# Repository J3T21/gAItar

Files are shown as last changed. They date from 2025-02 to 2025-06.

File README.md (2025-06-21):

# gAItar
Final Year Masters Electronic and Information Engineering project: A mechatronic interface to play an acoustic guitar with some AI elements.

gAItar Demo Video (https://youtu.be/pzkTf3Y7SAQ)

## User Guide

### Introduction
Welcome to gAItar! This guide will help you understand how to set up and use the gAItar system.

### Setup Instructions

#### Software Setup

##### Backend API (`gAItar_api`)
1.  Navigate to the `gAItar_api/backend` directory in your terminal.
2.  It's recommended to create and activate a Python virtual environment:
    *   `python -m venv venv`
    *   On Windows: `venv\Scripts\activate`
    *   On macOS/Linux: `source venv/bin/activate`
3.  Install Python dependencies: `pip install -r requirements.txt` (Ensure you have a `requirements.txt` file in this directory listing libraries like `fastapi`, `uvicorn`, `torch`, `huggingface_hub`, `python-multipart`, `mido`, `miditok`, `basic-pitch`, `tensorflow`, `pretty_midi`).
4.  Run the FastAPI server: `uvicorn main:app --reload`
    *   The API will be available at `http://localhost:8000`.

##### User Interface (`UI/gaitar_ui`)
1.  Navigate to the `UI/gaitar_ui` directory in your terminal.
2.  Install Node.js dependencies: `npm install`
3.  Start the development server: `npm start`
    *   The UI will be accessible at `http://localhost:3000`.
4.  **Important:** Verify and update the API base URLs in `UI/gaitar_ui/src/api.js`:
    *   `backend_api`: Should point to your backend API (e.g., `http://localhost:8000`).
    *   `esp32`: Should point to your ESP32's IP address (e.g., `http://192.168.113.200`).

##### ESP32 Firmware (`gAItar_esp32`)
1.  Open the `gAItar_esp32` project folder in VS Code with PlatformIO extension.
2.  In `gAItar_esp32/src/main.cpp`:
    *   Update the `ssid` and `password` variables with your Wi-Fi network credentials. The current configuration is set for an Android mobile hotspot. Ensure this network is the same one your computer (running the UI and backend) is connected to.
    *   The ESP32 attempts to configure a static IP address (e.g., `192.168.113.200` as seen in the code). The actual IP address will be displayed in the Serial Monitor upon successful connection. Ensure this IP matches the `baseURL` for `esp32` in `UI/gaitar_ui/src/api.js`. Also change this to match the websockets in the `upload.js` and `playbackinfo.js` components (this caused me much pain in the past).
    *   3.  Build and upload the firmware to the ESP32 board using PlatformIO.

##### Adafruit Grand Central Firmware (`gAItar_arduino`)
1.  Open the `gAItar_arduino` project folder in VS Code with PlatformIO extension.
2.  The firmware should generally not require changes for basic operation. Pin assignments for solenoids and servos are defined in `gAItar_arduino/src/globals.cpp`. Ensure these match your physical wiring.
3.  Build and upload the firmware to the Adafruit Grand Central board using PlatformIO.

### Using the gAItar Interface

#### Main Interface Overview
*   **Search & Playlist:**
    *   Use the search bar to find songs by title.
    *   Filter songs by artist or genre using the dropdowns.
    *   Click "Play" to play a song immediately or "Add to Playlist" to add it to the current queue.
    *   Manage the current playlist (e.g., reorder, remove songs).
*   **Playback Controls:**
    *   Use the Play, Pause, Skip Forward, Skip Backward, and Shuffle buttons to control playback on the physical guitar.
*   **MIDI Generation (`GenMIDI`):**
    *   Enter a text prompt describing the music you want to generate (e.g., "a sad blues riff in E minor").
    *   Click "Generate MIDI". The generated MIDI can be played in the browser or uploaded to the song upload form.
*   **Song Upload (`Upload`):**
    *   Select a MIDI file (`.mid` or `.midi`).
    *   Enter the Title, Artist, and Genre for the song.
    *   You can add new artists or genres if they are not in the existing dropdowns.
    *   Click "Upload". This will send the MIDI to the backend for processing and then transfer the processed data to the ESP32.
*   **Voice to MIDI (`VoiceToMIDI`):**
    *   Record audio using your microphone.
    *   Convert the recorded audio to a MIDI file.
    *   The generated MIDI can be played, downloaded, or sent to the Upload form.
*   **Voice Control:**
    *   Use voice commands to control playback (e.g., "Play song [Title]", "Pause", "Next song"). Refer to the UI for available commands and status.

### Troubleshooting
*   **Cannot connect to ESP32:**
    *   Verify the ESP32's IP address in `UI/gaitar_ui/src/api.js` matches the IP shown in the ESP32's serial output.
    *   Ensure the ESP32 is connected to the same Wi-Fi network as the computer running the UI.
    *   Check the ESP32 serial monitor for error messages (e.g., Wi-Fi connection issues, SPIFFS errors).
*   **MIDI generation fails:**
    *   Ensure the backend API (`gAItar_api`) is running and accessible at `http://localhost:8000`.
    *   Check the backend console for error messages (e.g., model loading issues, Hugging Face Hub connection).
*   **Song upload fails:**
    *   Ensure both the backend API and ESP32 are operational and connected.
    *   Check the browser console, backend console, and ESP32 serial monitor for specific error messages.
    *   Verify SPIFFS on the ESP32 is working correctly (it's formatted on ESP32 startup).
*   **Playback issues on the guitar:**
    *   Check wiring to solenoids and servos.
    *   Verify pin configurations in `gAItar_arduino/src/globals.cpp`.
    *   Monitor serial output from the Adafruit Grand Central for any errors during playback.

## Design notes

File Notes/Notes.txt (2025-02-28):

Mini solenoids seem to be just about strong enough
Need 5v for gate of current mosfets - could get 3.3V Vth https://www.mouser.co.uk/ProductDetail/Infineon-Technologies/IRFZ34NPBF?qs=9%252BKlkBgLFf3Kc9ZWbyua6Q%3D%3D
Guitar thickness = 11.3cm, 4cm between inner servo flanges, 3cm between 2 consecutive servo flanges, servo 17mm thick, m2.5 bolt holes, height above guitar lower edge 19mm, bar thickness <15mm, body to hole center ~3mm maybe check.
Guitar width ~30cm
https://github.com/natecdr/tuttut midi -> tab

1. get single channel guitar only midi (python)
2. convert to intermediate representation string and fret number greedy? (python)
3. read intermediate representation (cpp)
4. convert to movements/or sounds in model(cpp)

1. Can either be different tracs for different instruments or single track, just merge and get rid of non guitar sounds (at least for now)
Program_change messages specify which channel contains which instrument, use this to filter
2. Note assigning algorithm deal with decisions/conflicts. start with classical midi for algo dev -strictly guitar

https://www.twilio.com/en-us/blog/working-with-midi-data-in-python-using-mido

around delay of 60 seems to be min delay
if notes are "simultaneous" delay after all simultaneous notes (no delays in between).

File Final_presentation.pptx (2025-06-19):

## gAItar

A robotically actuated acoustic guitar with generative AI

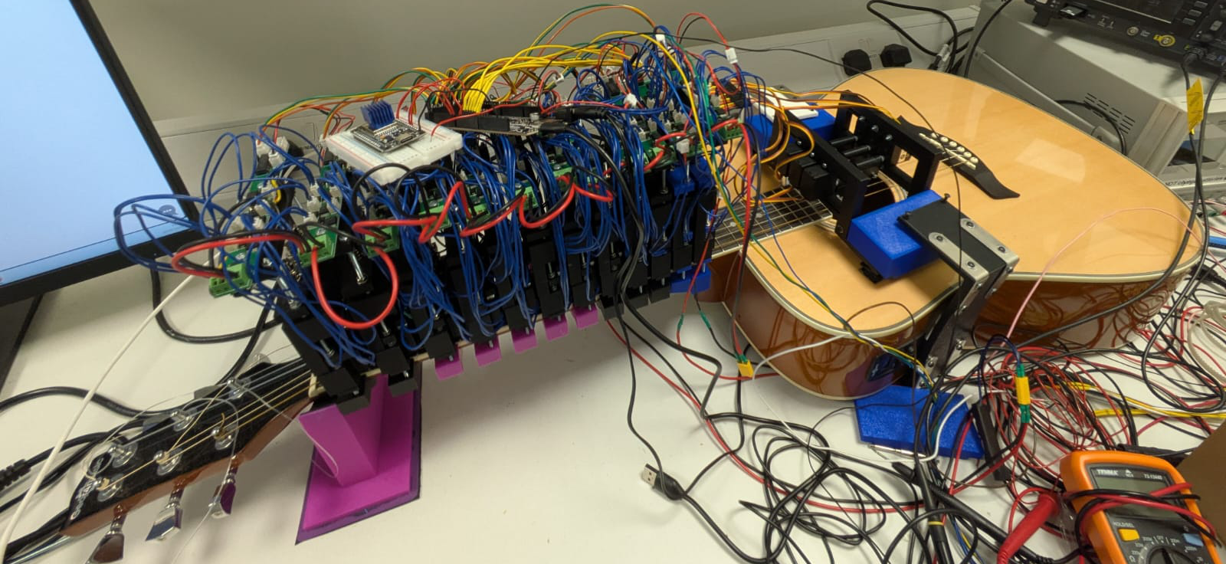
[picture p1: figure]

## Video Demonstration

https://youtu.be/pzkTf3Y7SAQ

## System Overview

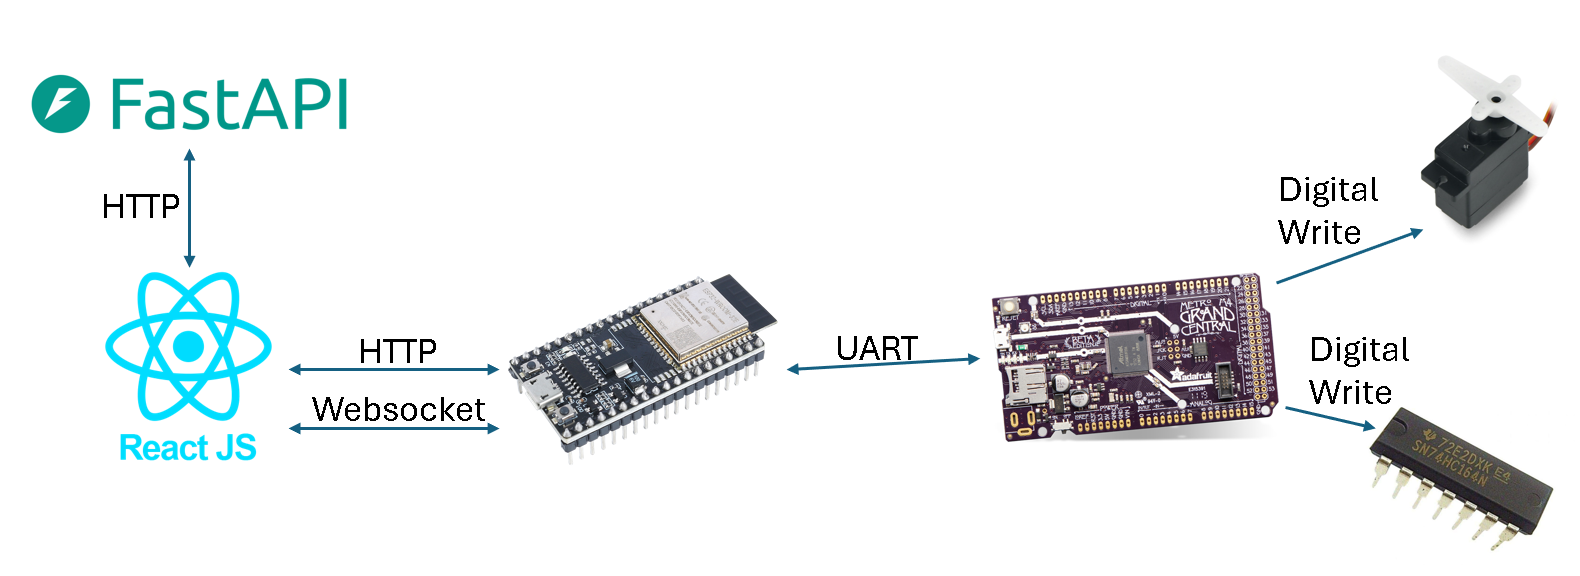
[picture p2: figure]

## Backend endpoints

POST /upload-midi-binary
POST /upload-midi (legacy)
POST /generate-midi/
Post /convert-audio-to-midi/

## /upload-midi-binary overview

Endpoint: POST /upload-midi-binary
Receives: A user-uploaded MIDI file and its song metadata.
Translates: Converts MIDI notes into a playable sequence of guitar events (string, fret, time).
Optimizes: Serializes these events into a custom, highly compact binary format designed for the microcontroller's limited memory.
Delivers: Returns the binary data to the frontend for transfer to the ESP32.

## MIDI to Guitar

Metadata extraction
Note to guitar mapping
Melodic track isolation
Merging and time normalisation
Event encoding
JSON formatting
Extract global timing info
Remove percussion (MIDI track 9) and empty tracks
Combine melodic tracks, convert time to absolute ms
Greedy algorithm to map not to string, fret pair, lowest note first
Encode each note on and off event: Timing, string number, fret number
Sort events chronologically and wrap into JSON structure

## Playback instruction format

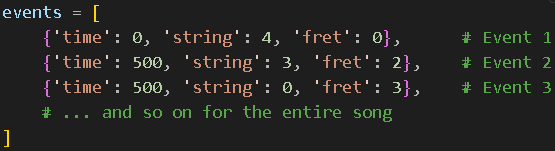
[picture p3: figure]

JSON event format

30x reduction in file sizes

Binary encoding

Byte 0 | Byte 1 | Byte 2 | Byte 3 | Byte 4
Time ms (unsigned long) | | | | Guitar Mapping

Byte 4
Bit 7 | Bit 6 | Bit 5 | Bit 4 | Bit 3 | Bit 2 | Bit 1 | Bit 0
0 | 1 | 1 | 0 | 0 | 0 | 1 | 0
String = [7:5] | | | Fret = [4:0]

## /generate-midi/ overview

User input
JSON payload from React.js frontend
Model inference
Text2midi T5 transformer model
Token generation
Text based musical tokens
Decode to midi
Miditok library used to turn tokens into midi file
Output
MIDI file returned to frontend

Text2midi neural network usage

## /audio-to-midi/ overview

User Input
Upload
Output
Clip recorded as wav file from frontend
Wav file is uploaded to /audio-to-midi/ endpoint
Automated Musical Transcription (AMT)
Basic Pitch Neural network by Spotify research MIDI output
Send MIDI file to frontend for user decision

## Frontend overview (React.js)

Controls.js
Playback controls
Search.js
Search and filter for songs
Playlist.js
Manages song queue
Upload.js
Form for upload, posts to backend, websocket for progress
GenMIDI.js
Generate MIDI from text prompt, posts text to backend
VoiceToMIDI.js
User microphone input, sends recording to backend for MIDI transcription
VoiceControl.js
Uses browser Speech Recognition API to respond to commands
PLaybackInfo.js
Websocket for live playback info

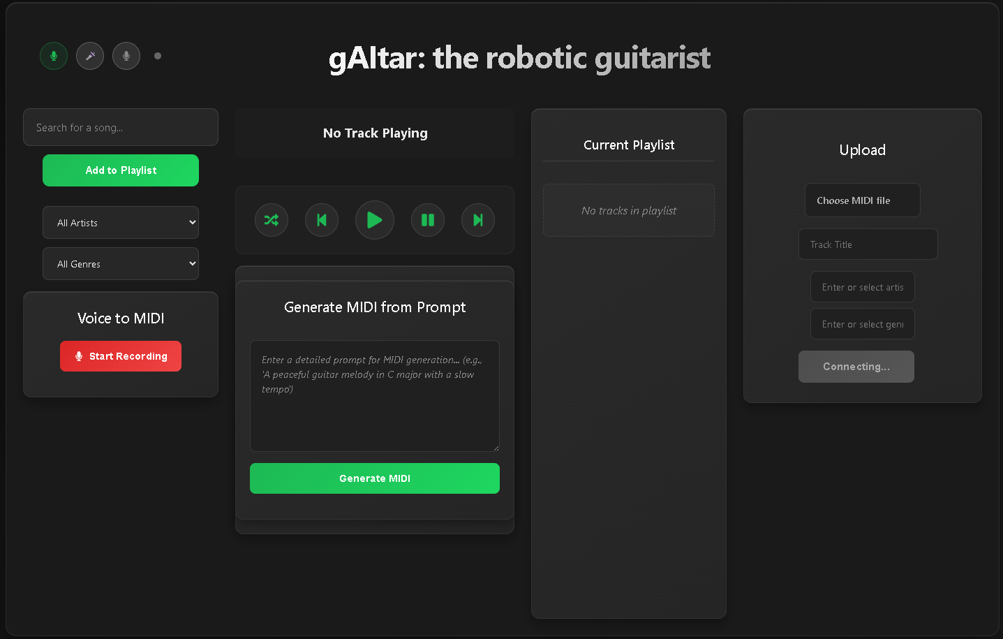
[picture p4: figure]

## ESP32 Wi-Fi Co-processor

- Web Server – (Play, Pause, Skip, Upload, List)
- Wi-Fi Connection – (Local network)
- UART bridge – (forwards control commands and files over UART)
- Real-Time status – (handles information from UART and sends to frontend via Websocket)

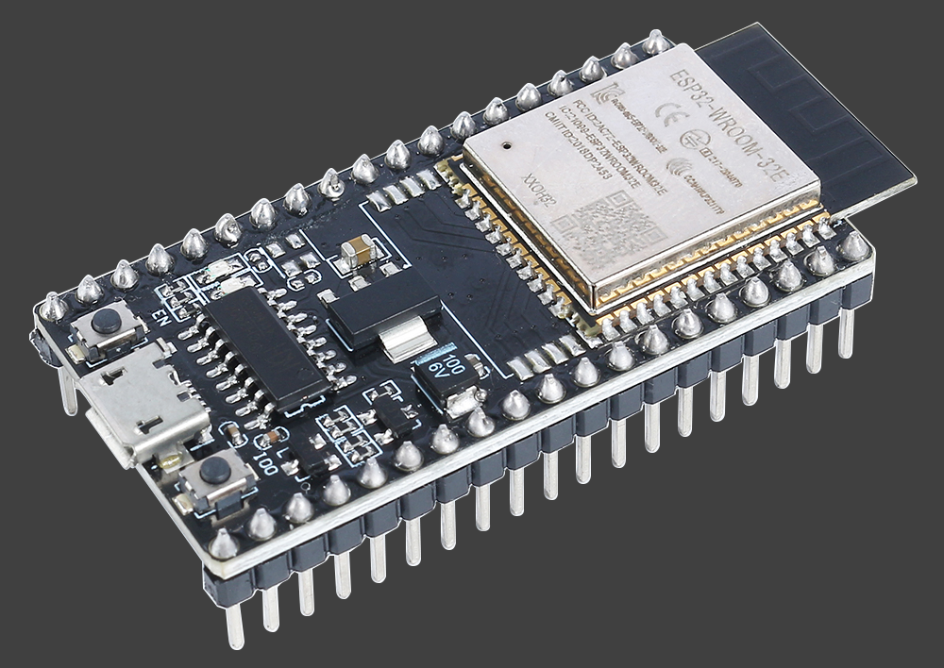
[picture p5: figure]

## Adafruit Grand Central Hardware Controller

- Respond to UART commands from ESP32
- Store binary IR files on microSD card
- Parse IR files to control actuators
- Send status updates over UART to ESP32
- RTOS tasks: file receiver, instruction receiver, playback

## Adafruit Grand Central

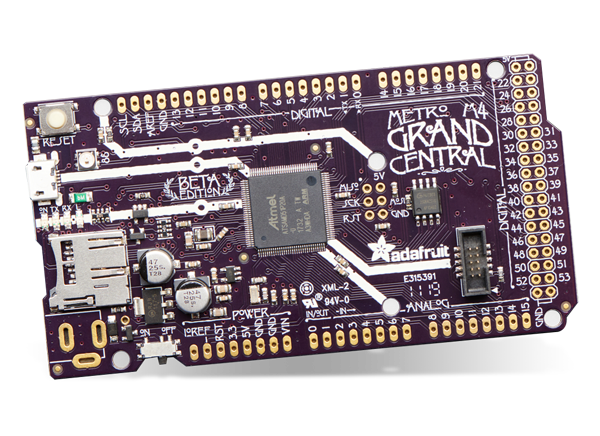
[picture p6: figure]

70 GPIOs – tons of I/O for motors, sensors, and controls
22 PWM outputs – precise motor/actuator control
microSD Card Slot – expandable file storage
8 SERCOMs – flexible I2C/SPI/UART communication
120 MHz Cortex-M4 + FPU/DSP – fast, real-time processing
1MB Flash / 256KB RAM – enough for complex logic and buffering

## Command structure

Play
[PLAY]:{“title”: “Entertainer”, “artist”: “Joplin”, “genre”: “Ragtime”}
Pause
“Pause” current song is paused with offsets calculated and stored for playing the same song
List
“List” traverses microSD card and lists all files and sends over UART

## File upload

MIDI file uploaded by user
MIDI file sent to backend for translation to binary
File sent to Grand Central via UART
File deleted from ESP32 SPIFFS
Binary file returned to frontend and sent to ESP32
File saved to ESP32 SPIFFS
File saved to microSD card

Status updates sent to ESP32 via UART

## UART file upload TX state machine

IDLE
OPEN_FILE
SEND_HEADER
WAIT_HEADER_ACK
SEND_CHUNK
Wait for final POST chunk from frontend (entire file saved to SPIFFS)
Open SPIFFS file, get size and clear UART buffer
Send START:<path>:SIZE:<size>
Start ACK timer
Wait for ACK:START:SIZE:<size>
Read chunk from SPIFFS file
Send CHUNK:<id>:SIZE:<size>
Send chunk data
WAIT_CHUNK_ACK
Wait for ACK:CHUNK:<id>
CLEANUP
Close and Delete SPIFFS file

ACK valid

Invalid ACK retry

Invalid ACK recvd retry

ACK valid

## UART file upload RX state machine

PARSE_HEADER
OPEN_FILE
PARSE_CHUNK_HEADER
READ_CHUNK
Wait for START:<path>:<size>
Create directories
Open file for writing
Send “ACK:START:SIZE:<filesize>
Wait for CHUNK:<id>:<size>
Accumulate chunk data bytes
Check chunk id correctness
When data bytes is the size of the expected chunk write to file
DONE
Send “ACK:CHUNK:<chunk id>”

Valid header

All chunks received

More chunks needed

## Status updates

Playback status
Instruction UART
Upload status
Calculated on ESP32 side from state machine
ESP32 monitors UART and sends via Websocket
STATUS:{“currentTime”:<ms>,”totalTime”:<ms>}
Sent to UI via Websocket

## Actuation hardware

6 Servos (1 per string)
72 linear solenoids (discrete, up to 12th fret)
12 PCBs with shift registers and MOSFET drivers for solenoids (fret wise)

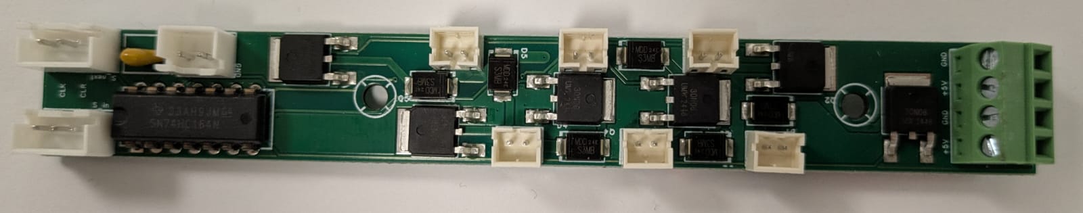
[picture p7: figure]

## Actuation control logic

- Servos toggle, damping position
- Binary file unpacked event by event
event[7:5] is string, event[4:0] fret (5’d31 is string off event)
- Each string mapped to a bit in fretStates byte
- Eg to press B(2), D(4) and A(5) string on the 3rd fret:
fretStates[2] = 0x02|0x10|0x80 = 8’b10010010 = 0x92

## Physical Design

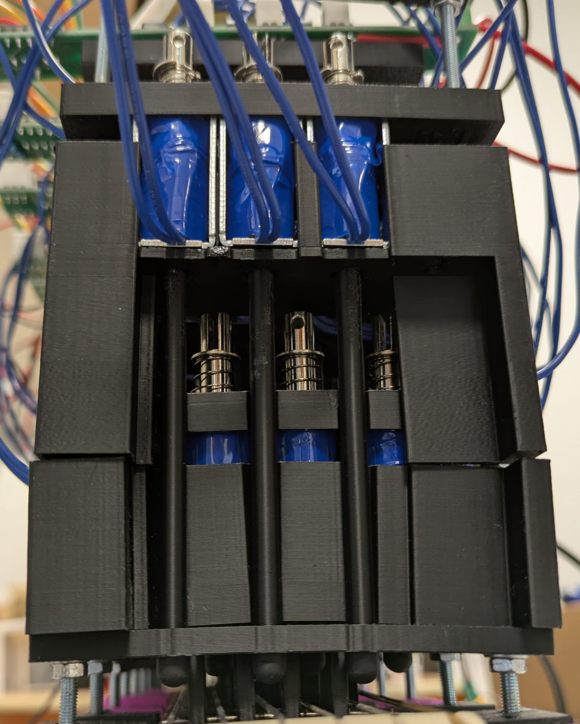
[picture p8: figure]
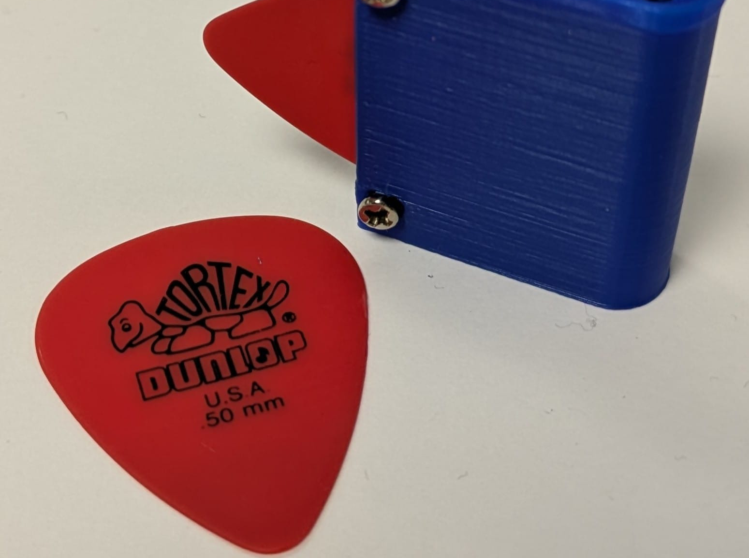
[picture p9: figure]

LH actuators
Linear solenoids
Fret wise clamping system
Biomimetic end effector
RH actuators
2Kg Servos
Clamp + bridge system
Plectrum holders

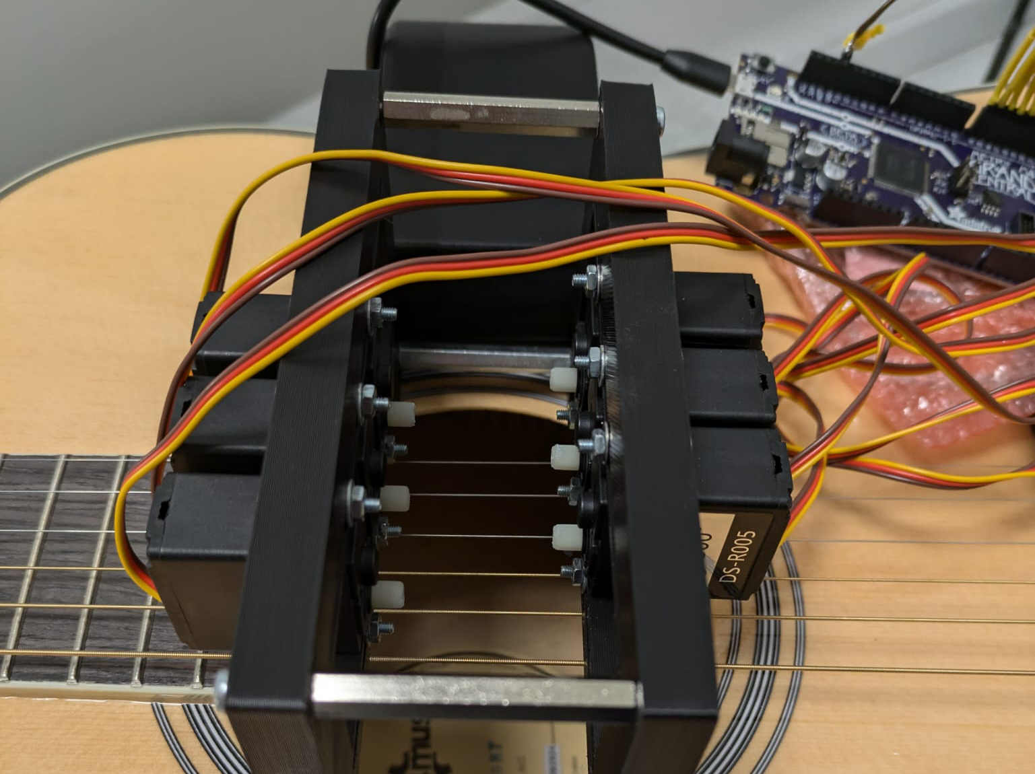
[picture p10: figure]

## Testing and Evaluation methods

Test plans (qualitative and quantitative where applicable)
Survey (primarily college students)
Comparison to existing examples

## Test Results

Areas for improvement
Actuation noise was 78.4dB, target of 50dB
Plucking/strumming frequency was 3Hz, target 5Hz
Search voice command did not work reliably
No error message on unrecognized command
GUI didn’t adapt well to different screen sizes

## Survey Results

System Usability
89% found GUI easy to use
Performance ratings
Voice Features: 53% rated good/excellent
92% rated system as responsive
4.23/5 average usability score
86% found system reliable
80% satisfied with MIDI file handling
Audio Quality: 3.7/5 average
Hardware Performance: 59% rated good/excellent
Music Generation: 68% rated good/excellent
Demonstration suitability
83% found system inspiring
82% believed it would capture audience interest
96% said it demonstrates engineering concepts well
8.3/10 average score as open-day demonstrator
80% likely to explore electronics further after seeing it

## Conclusion

Project Success
Key Achievement
Core Impact
Met initial requirements
Survey validated system as effective for intended purpose
A fully integrated, end to end system
System demonstrates interdisciplinary nature and knowledge learnt from EIE

## Future Work

Right Hand mechanism
Left Hand noise
AI & AMT
Musical Dynamics
Integrate faster actuators to enable tremolo effect >5Hz
Extra DOF for RH mechanism
Include MIDI velocity in encoding
Redesign LH mechanism targeting quiet actuation
Improve GenAI component
Explore more advanced models
Data Format Optimisation (DONE)
Replace JSON format with compact custom format

## Thanks for listening Any questions?

jet21@ic.ac.uk

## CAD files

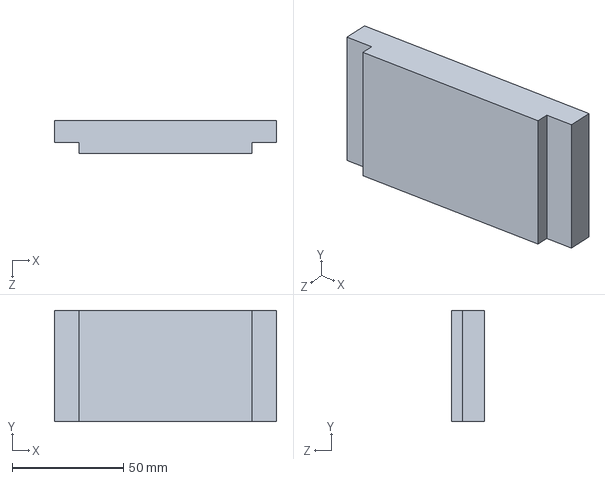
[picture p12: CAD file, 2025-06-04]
solidworks/clamp_plate.SLDPRT
100.0 x 50.0 x 15.0 mm

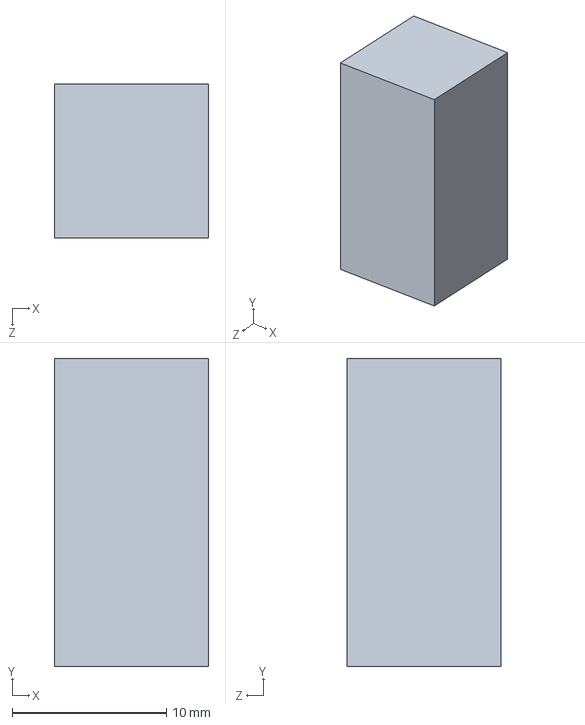
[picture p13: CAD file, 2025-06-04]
solidworks/Part1.SLDPRT
10.0 x 20.0 x 10.0 mm

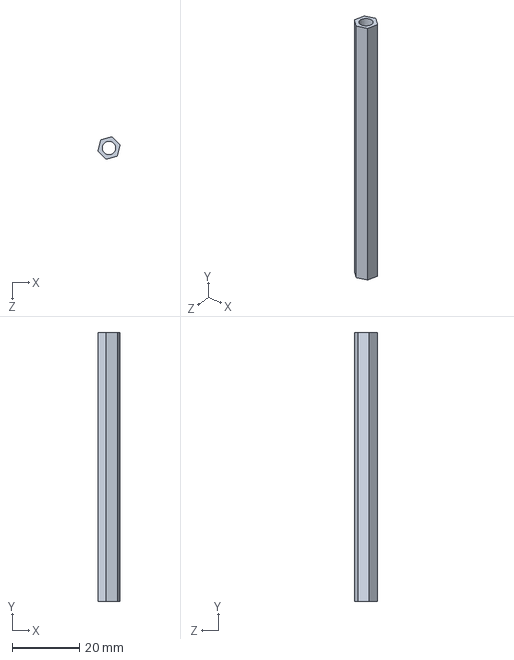
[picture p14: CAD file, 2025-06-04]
solidworks/spacer70.SLDPRT
6.67 x 80.0 x 6.71 mm

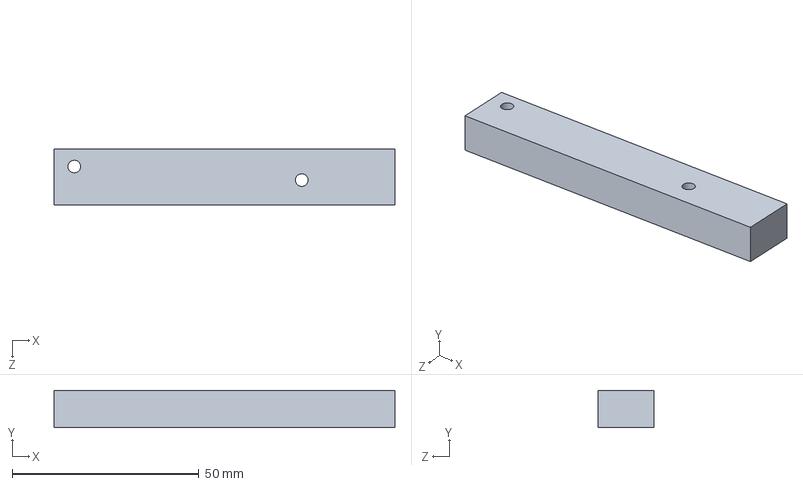
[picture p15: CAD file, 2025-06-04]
solidworks/servolegs.SLDPRT
91.4 x 10.0 x 15.0 mm

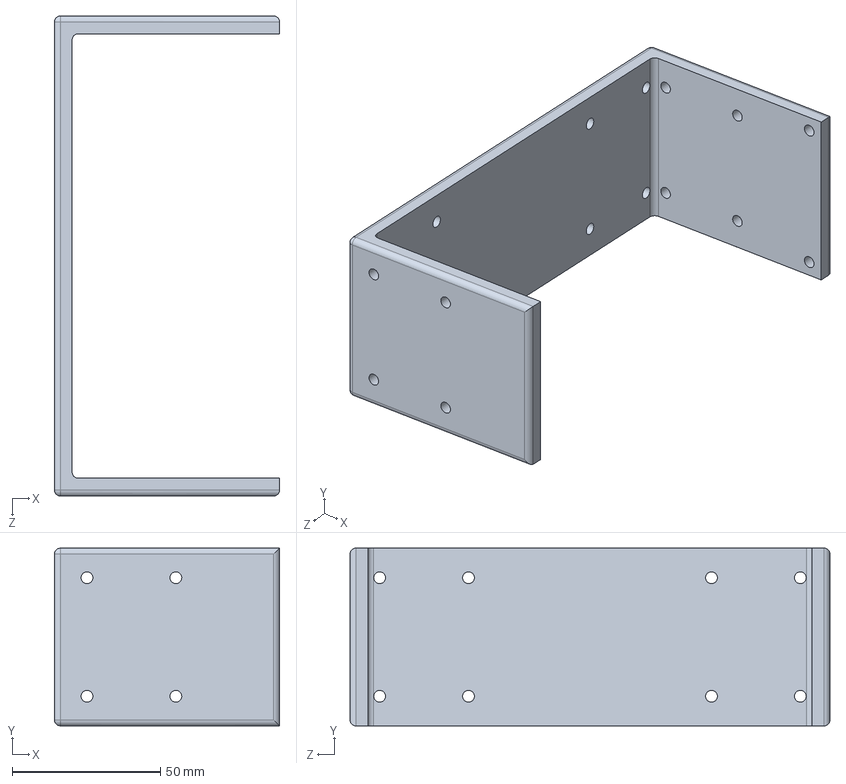
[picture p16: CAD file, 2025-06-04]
solidworks/slimclamp.SLDPRT
76.0 x 60.0 x 162.0 mm

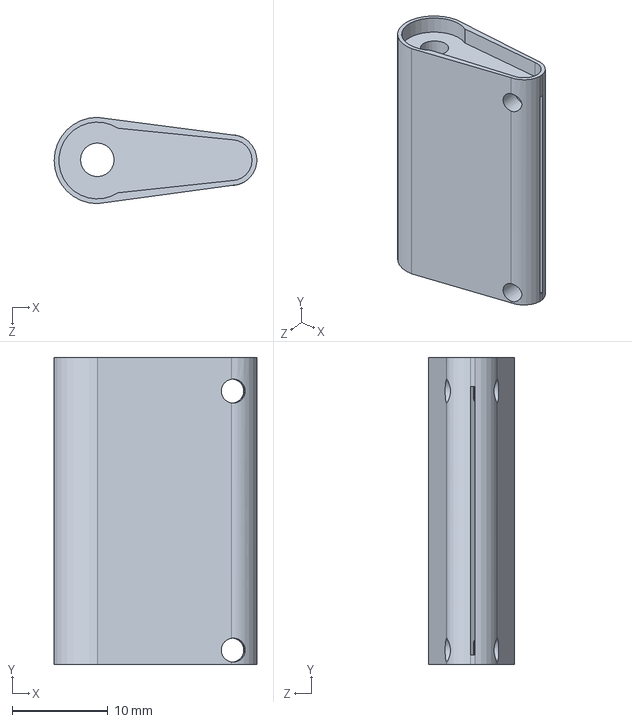
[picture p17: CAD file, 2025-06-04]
solidworks/rh_slotted_plectrum_flex.SLDPRT
21.1 x 32.0 x 9.00 mm

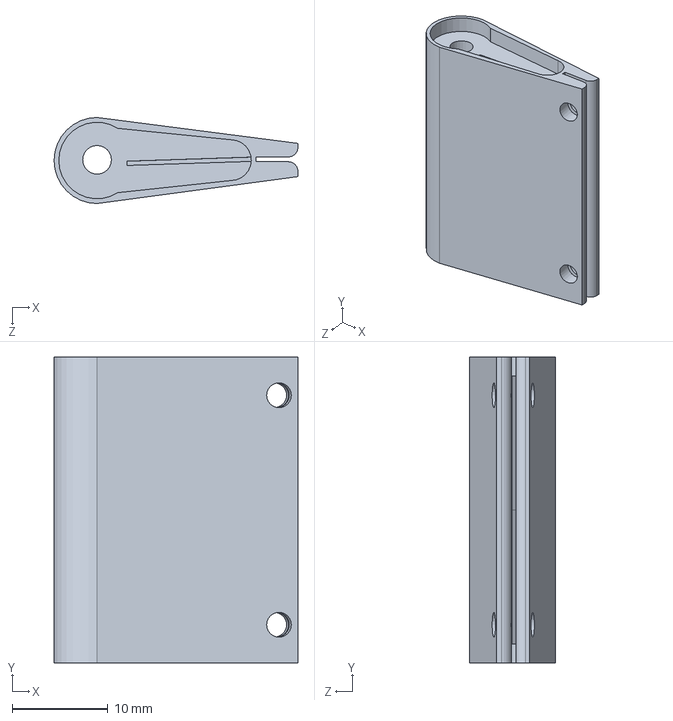
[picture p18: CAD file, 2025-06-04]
solidworks/rh_slotted_plectrum.SLDPRT
25.5 x 32.0 x 9.00 mm

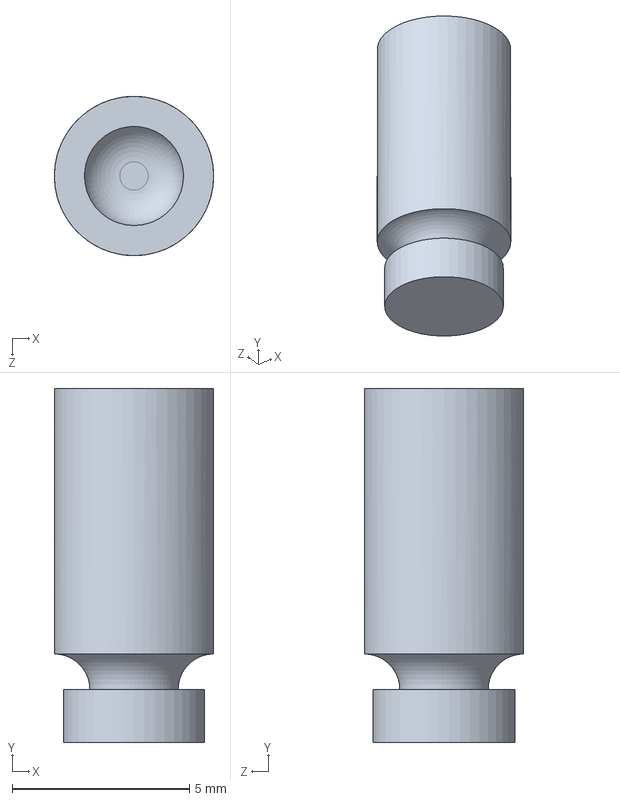
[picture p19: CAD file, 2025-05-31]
solidworks/lh_finger_2m.SLDPRT
4.50 x 10.0 x 4.50 mm

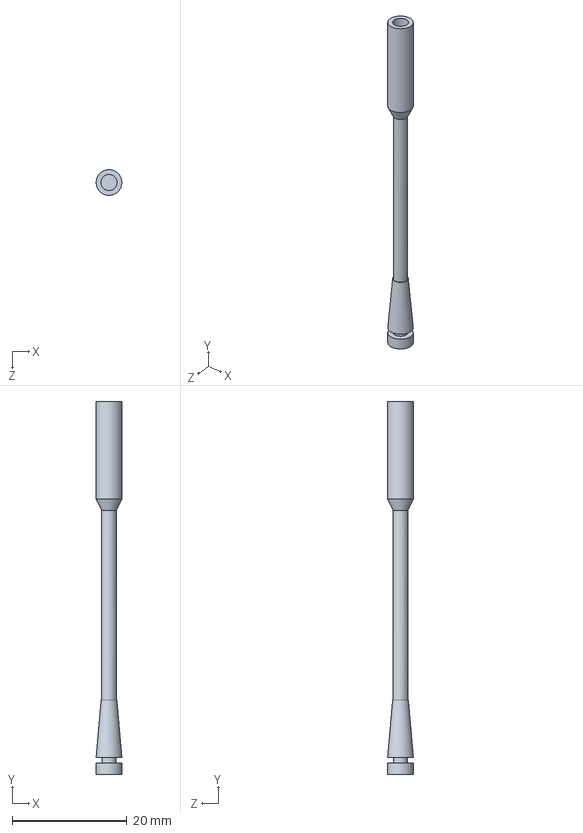
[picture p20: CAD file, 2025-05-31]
solidworks/lh_fingerhigh_deep_m.SLDPRT
4.50 x 65.0 x 4.50 mm

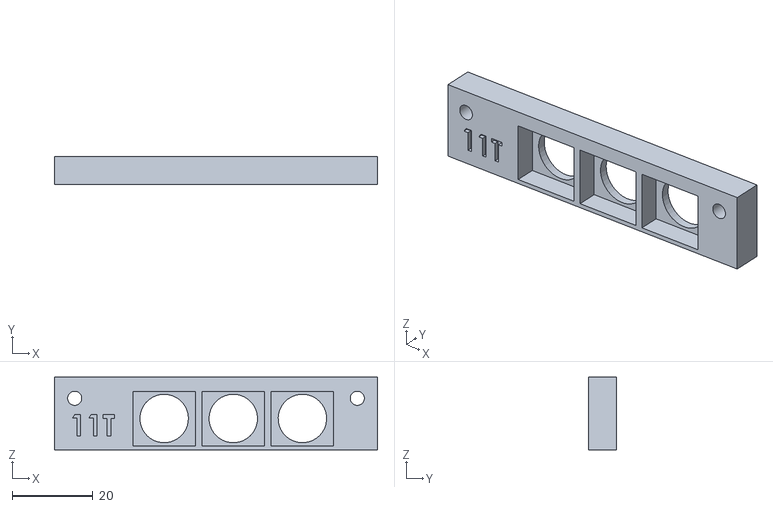
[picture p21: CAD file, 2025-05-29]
solidworks/fret11_lidtop.STL
80.0 x 7.00 x 18.0

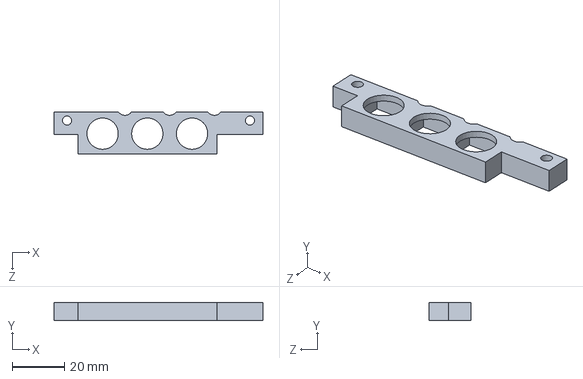
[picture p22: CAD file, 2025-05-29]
solidworks/fret11_lidbottom.SLDPRT
80.0 x 7.00 x 16.0 mm

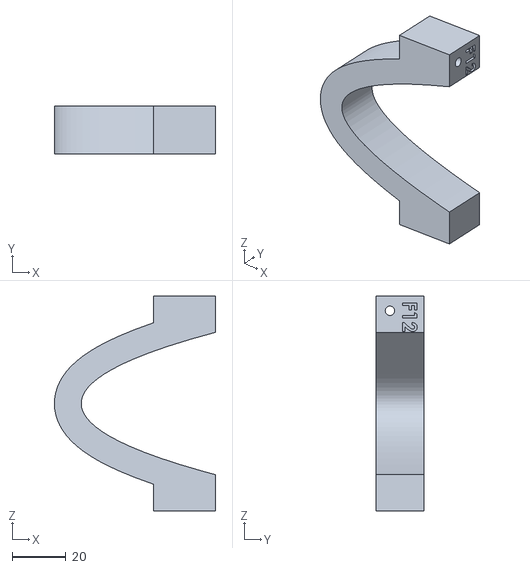
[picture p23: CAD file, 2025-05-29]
solidworks/fret12_clamp.STL
60.0 x 18.0 x 80.0

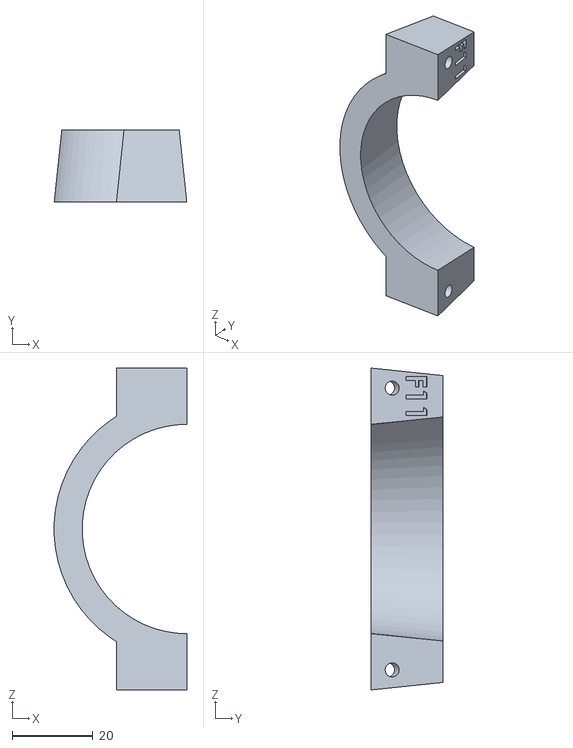
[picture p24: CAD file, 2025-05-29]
solidworks/fret11_clamp.STL
33.0 x 18.0 x 80.0

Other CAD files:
solidworks/solenoidmount_assembly.SLDASM
solidworks/spacer80.STL
solidworks/fret12_lidtop.SLDPRT
solidworks/fret11_12_clamp.SLDPRT
solidworks/fret1_lidtop.SLDPRT
solidworks/Fret10_clampv2.SLDPRT
solidworks/Fret10_clampv2.STL
solidworks/Fret10_new.SLDPRT
solidworks/Fret10_new.STL
solidworks/Fret11_new.SLDPRT
solidworks/Fret11_new.STL
solidworks/Fret12_new.SLDPRT
solidworks/Fret12_new.STL
solidworks/Fret1_clamp.SLDPRT
solidworks/Fret1_clamp.STL
solidworks/Fret1_clampv2.SLDPRT
solidworks/Fret1_clampv2.STL
solidworks/Fret1_lid.SLDPRT
solidworks/Fret1_lid.STL
solidworks/Fret1_lid_e.SLDPRT
solidworks/Fret1_lid_e.STL
solidworks/Fret1_lid_e5.STL
solidworks/Fret1_lid_long.SLDPRT
solidworks/Fret1_lid_long.STL
solidworks/Fret1_new.SLDPRT
solidworks/Fret1_new.STL
solidworks/Fret2_clamp.SLDPRT
solidworks/Fret2_clamp.STL
solidworks/Fret2_clampv2.SLDPRT
solidworks/Fret2_clampv2.STL
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

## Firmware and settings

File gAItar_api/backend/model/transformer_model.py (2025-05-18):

# from aria.tokenizer import AbsTokenizer
# aria_tokenizer = AbsTokenizer()
import copy
import json
from typing import Optional, Any, Union, Callable
import torch.multiprocessing as mp
from torch.nn import DataParallel
import jsonlines
import math
import time
import torch
import os
import warnings
from tqdm import tqdm
from torch import Tensor
# from aria.tokenizer import AbsTokenizer
import pickle
from torch.nn import Module, LayerNorm, Dropout, Linear
from torch.nn.modules.container import ModuleList
from torch.nn.modules.activation import MultiheadAttention
from torch.multiprocessing import Process, set_start_method
from torch.nn.init import xavier_uniform_
import torch.nn.functional as F
import torch.nn as nn

from st_moe_pytorch import MoE
from st_moe_pytorch import SparseMoEBlock

from einops import rearrange

from transformers import T5Tokenizer, T5EncoderModel

import sys
import torch.distributed as dist
from torch.nn.parallel import DistributedDataParallel as DDP
from torch.utils.data import DataLoader, Dataset

import torch.profiler

from accelerate import Accelerator
import argparse  # Add this import

class CaptionDataset(Dataset):
    def __init__(self, captions):
        self.captions = captions

    def __len__(self):
        return len(self.captions)

    def __getitem__(self, idx):
        return self.captions[idx]

def custom_collate_fn(batch):
    captions = [item['caption'] for item in batch]
    locations = [item['location'] for item in batch]
    return captions, locations

def ensure_log_dir_exists(log_dir):
    if not os.path.exists(log_dir):
        os.makedirs(log_dir)

__all__ = ['Transformer', 'TransformerEncoder', 'TransformerDecoder', 'TransformerEncoderLayer', 'TransformerDecoderLayer']

def _generate_square_subsequent_mask(
        sz: int,
        device: Optional[torch.device] = None,
        dtype: Optional[torch.dtype] = None,
) -> Tensor:
    r"""Generate a square causal mask for the sequence.

    The masked positions are filled with float('-inf'). Unmasked positions are filled with float(0.0).
    """
    if device is None:
        device = torch.device('cpu')
    if dtype is None:
        dtype = torch.float32
    return torch.triu(
        torch.full((sz, sz), float('-inf'), dtype=dtype, device=device),
        diagonal=1,
    )


def _get_seq_len(
        src: Tensor,
        batch_first: bool
) -> Optional[int]:

    if src.is_nested:
        return None
    else:
        src_size = src.size()
        if len(src_size) == 2:
            # unbatched: S, E
            return src_size[0]
        else:
            # batched: B, S, E if batch_first else S, B, E
            seq_len_pos = 1 if batch_first else 0
            return src_size[seq_len_pos]


class PositionalEncoding(nn.Module):
    r"""Inject some information about the relative or absolute position of the tokens in the sequence.
        The positional encodings have the same dimension as the embeddings, so that the two can be summed.
        Here, we use sine and cosine functions of different frequencies.
    .. math:
        \text{PosEncoder}(pos, 2i) = sin(pos/10000^(2i/d_model))
        \text{PosEncoder}(pos, 2i+1) = cos(pos/10000^(2i/d_model))
        \text{where pos is the word position and i is the embed idx)
    Args:
        d_model: the embed dim (required).
        dropout: the dropout value (default=0.1).
        max_len: the max. length of the incoming sequence (default=5000).
    Examples:
        >>> pos_encoder = PositionalEncoding(d_model)
    """

    def __init__(self, d_model, dropout=0.1, max_len=5000):
        super(PositionalEncoding, self).__init__()
        self.dropout = nn.Dropout(p=dropout)

        pe = torch.zeros(max_len, d_model)
        position = torch.arange(0, max_len, dtype=torch.float).unsqueeze(1)
        div_term = torch.exp(torch.arange(0, d_model, 2).float() * (-math.log(10000.0) / d_model))
        pe[:, 0::2] = torch.sin(position * div_term)
        pe[:, 1::2] = torch.cos(position * div_term)
        pe = pe.unsqueeze(0).transpose(0, 1)
        # self.register_buffer('pe', pe)
        self.register_parameter('pe', nn.Parameter(pe, requires_grad=False))

    def forward(self, x):
        r"""Inputs of forward function
        Args:
            x: the sequence fed to the positional encoder model (required).
        Shape:
            x: [sequence length, batch size, embed dim]
            output: [sequence length, batch size, embed dim]
        Examples:
            >>> output = pos_encoder(x)
        """
        x = x + self.pe[:x.size(0), :]
        return self.dropout(x)


def precompute_freqs_cis(
    seq_len: int,
    n_elem: int,
    base: int = 10000,
    dtype: torch.dtype = torch.bfloat16,
):
    freqs = 1.0 / (
        base ** (torch.arange(0, n_elem, 2)[: (n_elem // 2)].float() / n_elem)
    )
    t = torch.arange(seq_len, device=freqs.device)
    freqs = torch.outer(t, freqs)
    freqs_cis = torch.polar(torch.ones_like(freqs), freqs)
    cache = torch.stack([freqs_cis.real, freqs_cis.imag], dim=-1)

    return cache.to(dtype=dtype)


@torch.jit.script
def apply_rotary_emb(x: torch.Tensor, freqs_cis: torch.Tensor) -> torch.Tensor:
    """
    In-place RoPE. Credits to Katherine Crowson:
    x shape (b_sz, n_head, s_len, d_head).
    cos, sin shape (s_len, d_head // 2).
    """

    x = x.permute(0, 2, 1, 3)
    d = x.shape[-1] // 2
    cos = freqs_cis[..., 0][None, :, None]
    sin = freqs_cis[..., 1][None, :, None]
    x1, x2 = x[..., :d], x[..., d : d * 2]
    tmp = x1.clone()
    # x1.mul_(cos).addcmul_(x2, sin, value=-1)
    # x2.mul_(cos).addcmul_(tmp, sin, value=1) ##was throwing some error: RuntimeError: Output 0 of SliceBackward0 is a view and is being modified inplace. This view is the output of a function that returns multiple views. Such functions do not allow the output views to be modified inplace. You should replace the inplace operation by an out-of-place one.
    x1_new = x1.mul(cos) - x2.mul(sin)
    x2_new = x2.mul(cos) + tmp.mul(sin)
    x = torch.cat((x1_new, x2_new), dim=-1)
    x = x.permute(0, 2, 1, 3)
    
    return x


class MultiHeadSelfAttention(nn.Module):
    r"""Multi-head self-attention module.

    Args:
        embed_dim (int): The input embedding dimension.
        num_heads (int, optional): The number of attention heads (default: 4).
        dropout (float, optional): The dropout probability (default: 0.1).
        device (torch.device, optional): The device to use (default: None).
        dtype (torch.dtype, optional): The data type to use (default: None).

    Attributes:
        dim_head (int): The dimension of each attention head.
        scale (float): The scaling factor for attention scores.
        heads (int): The number of attention heads.
        to_qkv (nn.Linear): Linear layer for projecting input to query, key, and value.
        to_out (nn.Linear): Linear layer for projecting attention output to the original embedding dimension.
        dropout (nn.Dropout): Dropout layer.

    """

    def __init__(
        self,
        embed_dim: int,
        num_heads: int = 4,
        dropout: float = 0.1,
        batch_first: bool = True,
        device: Optional[torch.device] = None,
        dtype: Optional[torch.dtype] = None,
    ):
        factory_kwargs = {'device': device, 'dtype': dtype}
        super().__init__()
        self.embed_dim = embed_dim
        self.batch_first = batch_first
        self.dim_head = embed_dim // num_heads
        self.scale = self.dim_head ** -0.5
        self.heads = num_heads
        hidden_dim = self.dim_head * num_heads
        self.to_qkv = nn.Linear(embed_dim, hidden_dim * 3, bias=False, **factory_kwargs)
        self.to_out = nn.Linear(hidden_dim, embed_dim, bias=False, **factory_kwargs)
        self.dropout = nn.Dropout(dropout)

    def forward(self, x: torch.Tensor, is_causal: bool = True) -> torch.Tensor:
        
        r"""Forward pass of the multi-head self-attention module.

        Args:
            x (torch.Tensor): The input tensor of shape (batch_size, sequence_length, embed_dim).

        Returns:
            torch.Tensor: The output tensor of shape (batch_size, sequence_length, embed_dim).

        """
        if not self.batch_first:
            x = x.transpose(0, 1)
        b, n, _ = x.size()
        q, k, v = torch.chunk(self.to_qkv(x), chunks=3, dim=-1)
        q, k, v = map(lambda t: t.contiguous().view(b, self.heads, n, -1), (q, k, v))

        self.freqs_cis = precompute_freqs_cis(
                seq_len=n,
                n_elem=self.embed_dim // self.heads,
                base=10000,
                dtype=x.dtype,
            ).to(x.device)
        freqs_cis = self.freqs_cis[: x.shape[1]]
        # q = apply_rotary_emb(q, freqs_cis)
        # k = apply_rotary_emb(k, freqs_cis)
        out = torch.nn.functional.scaled_dot_product_attention(q, k, v, is_causal=is_causal)
        out = out.contiguous().view(b, n, -1)
        out = self.dropout(out)
        return self.to_out(out)


class Transformer(Module):
    r"""A transformer model.

    User is able to modify the attributes as needed. The architecture
    is based on the paper "Attention Is All You Need". Ashish Vaswani, Noam Shazeer,
    Niki Parmar, Jakob Uszkoreit, Llion Jones, Aidan N Gomez, Lukasz Kaiser, and
    Illia Polosukhin. 2017. Attention is all you need. In Advances in Neural Information
    Processing Systems, pages 6000-6010.

    Args:
        d_model: the number of expected features in the encoder/decoder inputs (default=512).
        nhead: the number of heads in the multiheadattention models (default=8).
        num_encoder_layers: the number of sub-encoder-layers in the encoder (default=6).
        num_decoder_layers: the number of sub-decoder-layers in the decoder (default=6).
        dim_feedforward: the dimension of the feedforward network model (default=2048).
        use_moe: if True, use MoE instead of linear layer for feedforward network (default=False).
        dropout: the dropout value (default=0.1).
        activation: the activation function of encoder/decoder intermediate layer, can be a string
            ("relu" or "gelu") or a unary callable. Default: relu
        custom_encoder: custom encoder (default=None).
        custom_decoder: custom decoder (default=None).
        layer_norm_eps: the eps value in layer normalization components (default=1e-5).
        batch_first: If ``True``, then the input and output tensors are provided
            as (batch, seq, feature). Default: ``False`` (seq, batch, feature).
        norm_first: if ``True``, encoder and decoder layers will perform LayerNorms before
            other attention and feedforward operations, otherwise after. Default: ``False`` (after).
        bias: If set to ``False``, ``Linear`` and ``LayerNorm`` layers will not learn an additive
            bias. Default: ``True``.

    Examples::
        >>> transformer_model = nn.Transformer(nhead=16, num_encoder_layers=12)
        >>> src = torch.rand((32, 512))
        >>> tgt = torch.rand((32, 512, 30000))
        >>> out = transformer_model(src, tgt)

    Note: A full example to apply nn.Transformer module for the word language model is available in
    https://github.com/pytorch/examples/tree/master/word_language_model
    """

    def __init__(self, n_vocab: int = 30000, d_model: int = 512, nhead: int = 8, max_len: int = 5000,
                 num_decoder_layers: int = 6, dim_feedforward: int = 2048, use_moe: bool = False, 
                 num_experts: int = 16, dropout: float = 0.1, 
                 activation: Union[str, Callable[[Tensor], Tensor]] = F.relu,
                 layer_norm_eps: float = 1e-5, batch_first: bool = True, norm_first: bool = False,
                 bias: bool = True, device=None, dtype=None) -> None:
        factory_kwargs = {'device': device, 'dtype': dtype}
        super().__init__()
        torch._C._log_api_usage_once(f"torch.nn.modules.{self.__class__.__name__}")

        self.use_moe = use_moe

        self.input_emb = nn.Embedding(n_vocab, d_model, **factory_kwargs)
        self.pos_encoder = PositionalEncoding(d_model, dropout, max_len).to(device)

        # Load the FLAN-T5 encoder
        self.encoder = T5EncoderModel.from_pretrained("google/flan-t5-base").to(device)
        # Freeze the encoder
        for param in self.encoder.parameters():
            param.requires_grad = False

        decoder_layer = TransformerDecoderLayer(d_model, nhead, dim_feedforward, use_moe, num_experts, dropout,
                                                activation, layer_norm_eps, batch_first, norm_first,
                                                bias, **factory_kwargs)
        decoder_norm = LayerNorm(d_model, eps=layer_norm_eps, bias=bias, **factory_kwargs)
        self.decoder = TransformerDecoder(decoder_layer, num_decoder_layers, use_moe, decoder_norm)

        self.projection = nn.Linear(d_model, n_vocab).to(device)

        self._reset_parameters()

        self.d_model = d_model
        self.nhead = nhead

        self.batch_first = batch_first

    def forward(self, src: Tensor, src_mask: Tensor, tgt: Tensor, memory_mask: Optional[Tensor] = None,
                memory_key_padding_mask: Optional[Tensor] = None, tgt_is_causal: bool = True,
                memory_is_causal: bool = False) -> Tensor:
        r"""Take in and process masked source/target sequences.

        .. note::

            If a boolean tensor is provided for any of the [src/tgt/memory]_mask arguments, positions with a ``True`` value are
            not allowed to participate in the attention,
            which is the opposite of the definition for :attr:`attn_mask`
            in :func:`torch.nn.functional.scaled_dot_product_attention`.

        Args:
            src: the sequence to the encoder (required).
            src_attn_mask: the attention mask for the src sequence (required).
            tgt: the sequence to the decoder (required).
            tgt_mask: the additive mask for the tgt sequence (optional).
            memory_mask: the additive mask for the encoder output (optional).
            tgt_key_padding_mask: the Tensor mask for tgt keys per batch (optional).
            memory_key_padding_mask: the Tensor mask for memory keys per batch (optional).
            tgt_is_causal: If specified, applies a causal mask as ``tgt_mask``.
                Default: ``None``; try to detect a causal mask.
                Warning:
                ``tgt_is_causal`` provides a hint that ``tgt_mask`` is
                the causal mask. Providing incorrect hints can result in
                incorrect execution, including forward and backward
                compatibility.
            memory_is_causal: If specified, applies a causal mask as
                ``memory_mask``.
                Default: ``False``.
                Warning:
                ``memory_is_causal`` provides a hint that
                ``memory_mask`` is the causal mask. Providing incorrect
                hints can result in incorrect execution, including
                forward and backward compatibility.

        Shape:
            - src: :math:`(S, S)` for unbatched input, :math:`(S, N)` if `batch_first=False` or
              `(N, S)` if `batch_first=True`.
            - src_mask: :math:`(S, S)` or :math:`(N\cdot\text{num\_heads}, S, S)`.
            - tgt: :math:`(T, E)` for unbatched input, :math:`(T, N, E)` if `batch_first=False` or
              `(N, T, E)` if `batch_first=True`.
            - tgt_mask: :math:`(T, T)` or :math:`(N\cdot\text{num\_heads}, T, T)`.
            - memory_mask: :math:`(T, S)`.
            - src_key_padding_mask: :math:`(S)` for unbatched input otherwise :math:`(N, S)`.
            - tgt_key_padding_mask: :math:`(T)` for unbatched input otherwise :math:`(N, T)`.
            - memory_key_padding_mask: :math:`(S)` for unbatched input otherwise :math:`(N, S)`.

            Note: [src/tgt/memory]_mask ensures that position :math:`i` is allowed to attend the unmasked
            positions. If a BoolTensor is provided, positions with ``True``
            are not allowed to attend while ``False`` values will be unchanged. If a FloatTensor
            is provided, it will be added to the attention weight.
            [src/tgt/memory]_key_padding_mask provides specified elements in the key to be ignored by
            the attention. If a BoolTensor is provided, the positions with the
            value of ``True`` will be ignored while the position with the value of ``False`` will be unchanged.

            - output: :math:`(T, E)` for unbatched input, :math:`(T, N, E)` if `batch_first=False` or
              `(N, T, E)` if `batch_first=True`.

            Note: Due to the multi-head attention architecture in the transformer model,
            the output sequence length of a transformer is same as the input sequence
            (i.e. target) length of the decoder.

            where :math:`S` is the source sequence length, :math:`T` is the target sequence length, :math:`N` is the
            batch size, :math:`E` is the feature number

        Examples:
            >>> # xdoctest: +SKIP
            >>> output = transformer_model(src, tgt, src_mask=src_mask)
        """
        if src.dim() != tgt.dim():
            raise RuntimeError("the number of dimensions in src and tgt must be equal")

        memory = self.encoder(src, attention_mask=src_mask).last_hidden_state

        tgt = self.input_emb(tgt) * math.sqrt(self.d_model)
        tgt = self.pos_encoder(tgt)
        # tgt = tgt + tgt_pos
        
        if self.use_moe:
            with torch.cuda.amp.autocast(enabled =False):
                output, sum_total_aux_loss = self.decoder(tgt, memory, memory_mask=memory_mask,                                
                                    memory_key_padding_mask=memory_key_padding_mask,
                                    tgt_is_causal=tgt_is_causal, memory_is_causal=memory_is_causal)
        else:
            output = self.decoder(tgt, memory, memory_mask=memory_mask,                                
                                memory_key_padding_mask=memory_key_padding_mask,
                                tgt_is_causal=tgt_is_causal, memory_is_causal=memory_is_causal)
        
        output = self.projection(output)
        # output = F.log_softmax(output, dim=-1)

        if self.use_moe:
            return output, sum_total_aux_loss
        else:
            return output
        
    def generate(self, src: Tensor, src_mask: Tensor, max_len: int = 100, temperature: float = 1.0):
        ## ADD A START OF SEQUENCE TOKEN  <SS> token to the src tensor
        r"""Generate a sequence of tokens from the given inputs.

        Args:
            src: the sequence to the encoder (required).
            src_mask: the attention mask for the src sequence (required).
            max_len: the maximum length of the sequence to generate (default=100).
            temperature: the temperature for the softmax (default=1.0).

        Returns:
            torch.Tensor: The generated sequence of tokens.

        """
        if src.dim() != 2:
            raise RuntimeError("The src tensor should be 2-dimensional")
        tgt_fin = torch.full((src.size(0), 1), 1, dtype=torch.long, device=src.device)
        # values = [21631, 8, 10, 9, 6, 7, 17, 21632, 11474, 20626, 21151, 9426, 20627, 21143, 11476, 20640, 21143, 11477, 20655, 21145, 11476, 20669, 21145, 11477, 20683, 21145, 13527, 20697, 21146, 13529, 20712, 21145, 7013, 20769, 21143, 7006, 20769, 21143, 7006, 20769, 21141, 7009, 20769, 21143, 9426, 20797, 21144, 11474, 20797, 21173, 11476, 20812, 21144, 11477, 20826, 21145, 11476, 20840, 21145, 11477, 20855, 21145, 13527, 20869, 21144, 13529, 20883, 21143, 7006, 20940, 21139, 7013, 20940, 21140, 7006, 20940, 21147, 7009, 20940, 21147, 11474, 20969, 21144, 11474, 20969, 21170, 11476, 20983, 21144, 11477, 20997, 21145, 11476, 21012, 21144, 11477, 21026, 21144, 11479, 21040]
        # values_tensor = torch.tensor(values, dtype=torch.long, device=src.device)
        # tgt_fin = values_tensor.unsqueeze(0).repeat(src.size(0), 1)
        for i in tqdm(range(max_len)):
            max_index = tgt_fin.max()
            # assert max_index < 21634, "tgt_fin contains index out of range. Adjust n_vocab or fix tgt_fin indices."
            tgt = tgt_fin
            if self.use_moe:
                output, _ = self.froward(src, src_mask, tgt, memory_mask=None,                                
                                memory_key_padding_mask=None,
                                tgt_is_causal=True, memory_is_causal=False)
            else:
                output = self.forward(src, src_mask, tgt, memory_mask=None,                                
                                      memory_key_padding_mask=None,
                                      tgt_is_causal=True, memory_is_causal=False)          
            # logits = self.projection(output)
            logits = output
            output = F.log_softmax(logits/temperature, dim=-1)
            output = output.view(-1, output.size(-1))
            next_tokens = torch.multinomial(torch.exp(output), 1)[-1] # taking the last logit and adding to the sequence
            tgt_fin = torch.cat((tgt_fin, next_tokens.unsqueeze(-1)), dim=1)
        return tgt_fin[:, 1:]

    @staticmethod
    def generate_square_subsequent_mask(
            sz: int,
            device: Optional[torch.device] = None,
            dtype: Optional[torch.dtype] = None,
    ) -> Tensor:
        r"""Generate a square causal mask for the sequence.

        The masked positions are filled with float('-inf'). Unmasked positions are filled with float(0.0).
        """
        return _generate_square_subsequent_mask(sz, dtype=dtype, device=device)
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

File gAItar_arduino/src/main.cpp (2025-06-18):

#include <Arduino.h>
#include <Servo.h>
#include <SPI.h>
#include <SdFat.h>
#include <FreeRTOS_SAMD51.h>
#include "servo_toggle.h"
#include "pwm_shift_solenoid.h"
#include "shift_solenoid.h"
#include "test_funcs.h"
#include "globals.h"
#include "translate.h"
#include "uart_transfer.h"

volatile bool isPlaying = false;
volatile bool isPaused = false;
volatile bool newSongRequested = false;
char currentSongPath[128] = "";
size_t currentEventIndex = 0;
unsigned long startTime = 0;
unsigned long pauseOffset = 0;

SemaphoreHandle_t playbackSemaphore;
SemaphoreHandle_t sdSemaphore;

TaskHandle_t instructionTaskHandle;
TaskHandle_t playbackTaskHandle;
TaskHandle_t heapTaskHandle;
TaskHandle_t fileReceiverTaskHandle;

void fileReceiverTask(void *pvParameters){
    while (true){
        fileReceiverRTOS_char(dataUart);
        vTaskDelay(5 / portTICK_PERIOD_MS);
    }
}

void instructionTask(void *pvParameters) {
    Serial.println("Instruction task");
    while (true) {
        instructionReceiverRTOS(instructionUart); // Call the instruction receiver function to handle incoming instructions
        vTaskDelay(10 / portTICK_PERIOD_MS); // Delay to prevent task starvation
    }
}

void heapMonitorTask(void *pvParameters) {
    while (true) {
        Serial.print("Free heap: ");
        Serial.println(xPortGetFreeHeapSize());
        vTaskDelay(1000 / portTICK_PERIOD_MS); // Print every 1 second
    }
}

void playbackTask(void *pvParameters) {
    Serial.println("Playback task started");
    for (;;){
        if(xSemaphoreTake(playbackSemaphore, portMAX_DELAY)){
            playGuitarRTOS_Binary(currentSongPath);
            xSemaphoreGive(playbackSemaphore);
        }
        vTaskDelay(2 / portTICK_PERIOD_MS);
    }

}



void setup() {
    Serial.begin(115200); // Initialize serial communication or debugging
    dataUart.begin(BAUDRATE); // Initialize dataUart for UART communication
    instructionUart.begin(BAUDRATE); //intialize instructionUart for UART communication
    for (int i = 0; i < NUM_FRETS; i++)
    {
        pinMode(fretPins[i][0], OUTPUT); // Set clock pin as output
        pinMode(fretPins[i][1], OUTPUT); // Set data pin as output
        pinMode(fretPins[i][2], OUTPUT); // Set clear pin as output
        digitalWrite(fretPins[i][0], LOW); // Set clock pin LOW to start
        digitalWrite(fretPins[i][2], LOW); // Set clear pin LOW to clear the shift register initially
    }
    if (!sd.begin(83, SD_SCK_MHZ(25))) {
        Serial.println("SD card initialization failed!"); // SD card initialization failed
        return;
    } else {
        Serial.println("SD card initialized successfully!"); // SD card initialized successfully
    }

    listFilesOnSD();

    delay(100);


    
    playbackSemaphore = xSemaphoreCreateMutex();
    sdSemaphore = xSemaphoreCreateMutex();
    if (sdSemaphore == NULL) {
        Serial.println("Failed to create sdSemaphore!");
        while (1); // Halt if semaphore creation fails
    }
    if (playbackSemaphore == NULL) {
        Serial.println("Failed to create playbackSemaphore!");
        while (1); // Halt if semaphore creation fails
    }

    BaseType_t result = xTaskCreate(
        instructionTask, // Function to implement the task
        "Instruction Task", // Name of the task
        1024, // Stack size in words
        NULL, // Task input parameter
        3, // Priority of the task
        &instructionTaskHandle); // Task handle

    if (result != pdPASS){
        Serial.println("Instr task failed to create");
    }
    Serial.print("Free heap after instr");
    Serial.println(xPortGetFreeHeapSize());
    result = xTaskCreate(
        playbackTask, // Function to implement the task
        "Playback Task", // Name of the task
        2048, // Stack size in words
        NULL, // Task input parameter
        2, // Priority of the task
        &playbackTaskHandle); // Task handle
        if (result != pdPASS){
        Serial.println("Playback task failed to create");
    }
    Serial.print("Free heap after playback");
    Serial.println(xPortGetFreeHeapSize());
    result = xTaskCreate(
        fileReceiverTask,
        "FileReceiver Task",
        1024, // Stack size in words (adjust as needed)
        NULL,
        1, // Priority (set appropriately for your system)
        &fileReceiverTaskHandle
    );
    if (result != pdPASS) {
        Serial.println("FileReceiver task failed to create");
    }
    // result = xTaskCreate(
    //     heapMonitorTask,
    //     "Heap Monitor",
    //     256,
    //     NULL,
    //     1, // Lowest priority
    //     &heapTaskHandle
    // );   

    Serial.print("Free heap after file");
    Serial.println(xPortGetFreeHeapSize());
    vTaskStartScheduler();

    

}

void loop() {
    // testFretPWM(1, 1000, 10); 
    // testFret(1,1000,10);
//   fileReceiver_state(dataUart); // Call the file receiver function to handle incoming data
//   instructionReceiverJson(instructionUart); // Call the instruction receiver function to handle incoming instructions
   //testSerialControlservo();
  //testFret(1, 500, 12); // Test the fret function with a range of frets
  //testSerialControlservo();
    //testCombined(1,500);
  //playGuitarEventsOpen();
  //playGuitarFromFile("/Ragtime/Joplin/Entertainer.json");
//   if (isPlaying_glob){
//     playGuitarCommand();
//   }
}

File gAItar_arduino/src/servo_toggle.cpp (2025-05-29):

#include "servo_toggle.h"

// Constructor to initialize positions and attach the servo
ServoController::ServoController(int pin, int posA, int posB)
    : positionA(posA), positionB(posB), positionDamper((posA+posB+1)/2), currentPosition(posA), movingToB(true) {
    servo.attach(pin); // Attach the servo to the specified pin
    servo.write(positionA); // Set initial position
}

// Method to move the servo gradually with a delay
void ServoController::move(int delayMs) {
    int targetPosition = movingToB ? positionB : positionA;

    if (delayMs > 0) {
        // Gradual movement with delay to control speed
        int step = (targetPosition > currentPosition) ? 1 : -1;
        while (currentPosition != targetPosition) {
            currentPosition += step;
            servo.write(currentPosition); // Update the servo position
            delay(delayMs);               // Wait for the delay before next move
        }
    } else {
        // Immediate movement without delay
        servo.write(targetPosition);
        currentPosition = targetPosition;
    }

    movingToB = !movingToB; // Toggle the direction
}

void ServoController::damper() {
    // Move to the damper position
    servo.write(positionDamper);
    currentPosition = positionDamper;
}
void ServoController::release(int delayMs) {
    // Move to the opposite of the current target position
    int targetPosition = movingToB ? positionA : positionB;

    if (delayMs > 0) {
        // Gradual movement with delay to control speed
        int step = (targetPosition > currentPosition) ? 1 : -1;
        while (currentPosition != targetPosition) {
            currentPosition += step;
            servo.write(currentPosition); // Update the servo position
            delay(delayMs);               // Wait for the delay before next move
        }
    } else {
        // Immediate movement without delay
        servo.write(targetPosition);
        currentPosition = targetPosition;
    }

    // Note: We don't toggle movingToB here since this is a "release" back to previous position
}


PwmServoController::PwmServoController(int pwmPin, int posA, int posB, int minPulseMicros, int maxPulseMicros)
    : pin(pwmPin), positionA(posA), positionB(posB), currentPosition(posA), movingToB(true), 
      minPulse(minPulseMicros), maxPulse(maxPulseMicros) {

    pwmInstance = new SAMD_PWM(pin, 50.0f, 0.0f);  // Initialize with 50Hz frequency and 0% duty cycle
    pwmInstance->setPWM(pin, 50.0f, angleToDutyCycle(positionA));  // Set frequency to 50Hz, which is standard for servos

}

void PwmServoController::move(int delayMs) {
    int targetPosition = movingToB ? positionB : positionA;

    if (delayMs > 0) {
        // Gradual movement with delay to control speed
        int step = (targetPosition > currentPosition) ? 1 : -1;
        while (currentPosition != targetPosition) {
            currentPosition += step;
            int pwmValue = angleToDutyCycle(currentPosition);  // Get the corresponding PWM duty cycle
            pwmInstance->setPWM(pin, 50.0f, pwmValue);  // Set the PWM duty cycle
            delay(delayMs);            // Wait for the delay before the next step
        }
    } else {
        // Immediate movement without delay
        int pwmValue = angleToDutyCycle(targetPosition);  // Get the corresponding PWM duty cycle
        pwmInstance->setPWM(pin, 50.0f, pwmValue);  // Set the PWM duty cycle
        currentPosition = targetPosition;  // Update the current position
    }

    movingToB = !movingToB;  // Toggle the direction
}

float PwmServoController::angleToDutyCycle(int angle) {
    // Map the angle to the corresponding pulse width in microseconds
    float pulseWidthMicros = map(angle, 0, 300, 2500, 500);  // Map angle to pulse width (500µs to 2500µs)
    
    // Calculate the duty cycle: (pulse width / period) * 100
    float dutyCycle = (pulseWidthMicros / 20000.0) * 100;  // Period is 20000µs (50Hz PWM)

    // Return the duty cycle as a float (0.0% to 12.5%)
    return dutyCycle;
}

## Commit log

2024-12-15 mini solenoid tested
    [fretboard.SLDPRT, guitar.SLDPRT]
2024-12-17 platform io setup for gig arduino
2024-12-18 designed servo mounts and base servo code
2025-02-28 greedy algo cooking
    [Tarrega_Gran_Vals.mid.csv, Tarrega_Recuerdos_de_la_Alhambra.mid.csv, output_guitar_simulation.mid.csv]
2025-02-28 sld files
    [Fret1_clamp.SLDPRT, Fret1_clamp.STL, Fret1_new.SLDPRT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]
2025-04-04 cooking need to redesign pcb holder fol limited space
    [3dprints.xlsx, Beatles_White_Album__Blackbird.mid.csv, Fret10_clampv2.SLDPRT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]
2025-04-07 pwm experiments
2025-04-07 getting there need to test irl
    [PCB_plate.SLDPRT, PCB_plate_n.STL, clamp_plate.SLDPRT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]
2025-04-16 working on ui separate uart for upload and control
2025-05-04 this is mental
    [helmot_outer.SLDPRT, helmot_outer.STL, inside_helmet.SLDPRT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]
2025-05-20 shouldev fixed hanging by extra semaphore protection pwm testing time
    [main.cpp, translate.cpp, uart_transfer.cpp]
2025-05-29 pretty much done a few finishing touches maybe to do with the UI and what happens when clicking the song and the dropdown
    [fret11_12_clamp.SLDPRT, fret11_clamp.STL, fret11_guide.SLDPRT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]
2025-05-31 memory leaks fixed i hope, just a few ui tweaks + basic pitch backend integration?
    [lh_finger_2m.SLDPRT, lh_fingerhigh_deep_m.SLDPRT, lh_fingerhigh_deep_m.STL]
2025-05-31 added some voice stuff need to tidy up ui, make song library, try to polish translate.cpp and servo tuning
2025-06-04 need to stop implementing now!!
    [Part1.SLDPRT, Part1.STL, clamp_plate.SLDPRT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]
2025-06-04 i think i fixed it was likely a stackoverflow calling send status update every time playback task executed and it takes a while to send it on uart
    [main.cpp, translate.cpp, uart_transfer.cpp]
2025-06-05 lowk works small mem leak in playback still
    [translate.cpp, uart_transfer.cpp]
2025-06-16 added custom bin instruction format fixed everything inshallah
    [esp_server.cpp, main.cpp, translate.cpp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]
